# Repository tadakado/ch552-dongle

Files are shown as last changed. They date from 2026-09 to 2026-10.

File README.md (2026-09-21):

# CH552 USB HID ダミーデバイス

USB-A 直挿し基板に載せた CH552 を、キーボード + マウスの複合 HID として
認識させ、1 分ごとにマウスを 1 ドットだけ往復させてホストのスリープを
防ぐファーム。挿すだけで動き、操作は要らない。WS2812 で状態を表示する。

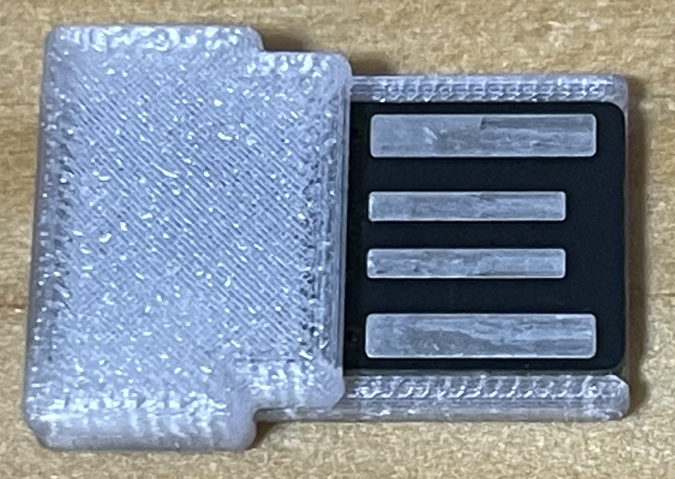
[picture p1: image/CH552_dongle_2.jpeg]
ケースまで組んだ状態


## 仕様

| | |
|---|---|
| MCU | CH552 (8051 互換 / フラッシュ 16KB のうちユーザ領域 14KB / xRAM 1KB) |
| クロック | 24MHz 固定 (VBUS 5V 直結。データシート上 24MHz は VCC 4.4V 超) |
| LED | WS2812C-2020 x1 @ P1.1 |
| タッチキー | TIN5 @ P1.7 (**既定では無効**) |
| USB | CDC-ACM + HID (キーボード + マウス) の複合デバイス |

### 既定の設定

`config.h` の既定値。挿せばすぐマウスを動かし始め、タッチキーは使わない。

| 設定 | 既定 | |
|---|---|---|
| `MODE_DEFAULT` | `MODE_WIGGLE` | 挿した直後から1分ごとにマウスを動かす |
| `TOUCH_ENABLE` | 0 | タッチキーを使わない |
| `TOUCH_LEARN_ENABLE` | 0 | タッチキーの閾値の学習をしない |
| `MODE_PERSIST` | 0 | モードを Data-Flash に覚えない |
| `CDC_DFU_1200BAUD` | 1 | 1200 baud でブートローダへ入れる |
| `SUSPEND_POLICY` | `SUSPEND_SLEEP` | ホストのサスペンド中は CH552 ごと眠る |

### モード

| モード | 動作 | LED |
|---|---|---|
| A: IDLE | 何もしない (HID として繋がっているだけ) | 緑 |
| B: WIGGLE | 1 分ごとにマウスを右へ 1、さらに 1 分後に左へ 1、を繰り返す | 赤 |

既定では**挿した直後からモード B** で、1 分後から動き始める。
切り替えはコンソールの `t` で行う (タッチキーを有効にすれば短押しでも
切り替えられる)。`MODE_DEFAULT` を `MODE_IDLE` にすると A から始まる。

切り替えた瞬間から 1 分を数え直すので、切り替えた直後にいきなり動くことは
ない。サスペンドなどで送れなかった場合は、溜まった回数をまとめて撃たずに
復帰後 1 回だけ動かして、そこから改めて 1 分を数える。

### LED の見方

| 表示 | 意味 |
|---|---|
| 消灯 | ホストがサスペンド中 (最優先) |
| 橙の呼吸 | まだ列挙されていない (SET_CONFIGURATION 未達) |
| 緑の呼吸 | モード A |
| 赤の呼吸 | モード B |

呼吸は 2.56 秒で一往復、最大輝度は 0x40。
タッチキーを有効にしたときの表示は「タッチキー (任意)」の節を参照。

### DFU (ブートローダ) への入り方

既定のビルドでは 3 系統。

1. **コンソールで `b` を入力。**
2. **1200 baud トリガ** (`CDC_DFU_1200BAUD`) — 開いて閉じるだけでよい。

   ```sh
   stty -f /dev/cu.usbmodemXXXX 1200
   ```

   CDC の SET_CONTROL_LINE_STATE で DTR が落ちたときに、ボーレートが 1200 なら
   0x3800 へ飛ぶ。Arduino Leonardo と同じ流儀。`screen` で入る場合は
   `Ctrl-A` → `K` で閉じること (`Ctrl-A` → `D` の detach ではポートが開いたままで
   DTR が落ちない)。

   **成功しても合図は出ない。** LED が消え、`/dev/cu.usbmodem*` が消えるだけ
   なので、失敗と見分けがつかない。WCH の ISP デバイス (VID 0x4348 /
   PID 0x55E0) が見えていれば入っている。

   ```sh
   ioreg -p IOUSB -l | grep -q 'idVendor" = 17224' && echo "ブートローダ"
   ```

   macOS の `/dev/cu.usbmodem*` は誰でも開けるので、ローカルの任意の
   プロセスがこのデバイスをブートローダに落とせる。0 にしても
   コンソールの `b` は残る (こちらも CDC を開ければ誰でも打てる)。
3. **ハードウェア** — D+ の 10kΩ プルアップパッドを短絡したまま挿す。
   ファームが USB ごと落ちたときの最後の砦なので、基板から省かないこと。

タッチキーを有効にすると、長押し 3 秒 (`TOUCH_LONGPRESS_DFU`) が 4 つめの
入口になる。

入ってしまったときは抜き差しすれば通常のファームに戻る。

## タッチキー (任意)

既定では無効。`TOUCH_ENABLE` を 1 にすると使える。

| 保持時間 | 触れている間の LED | 離したときの動作 |
|---|---|---|
| 〜1.0 秒 | 青 | モード切替 |
| 1.0〜3.0 秒 | シアン | 閾値を学習 (`TOUCH_LEARN_ENABLE` が 1 のときだけ) |
| 3.0 秒〜 | 白の点滅 | 何も起きない。3.6 秒まで持てばブートローダへ |

`TOUCH_LEARN_ENABLE` が 0 のときはシアンの区間ごと短押しに含まれ、
3.0 秒未満ならモード切替になる。学習が成功するとマゼンタ、採用されな
かったときは黄が点滅する。学習の書き込みは電源 ON から 2 回まで。

タッチキーを有効にすると、呼吸は指を近づけると明るくなり、閾値に
達した時点で 0x40 に張り付く。ホストのサスペンド中はタッチも効かない。

閾値は Data-Flash の保存値 > `TOUCH_THRESHOLD_DEFAULT` (0 以外のとき) >
起動時のノイズ実測からの自動決定、の順で決まる。手で決めるには
コンソールで `m` を流しながら指を当てて delta のピークを見て、`+` `-` で
合わせて `s` で焼く。`i` の `src=` で出どころが分かる。

## ハードウェア

基板は **EasyEDA Pro**、ケースは **Fusion 360** で設計した。
設計データは `hardware/` (基板) と `case/` (ケース) に置いてある。

### 基板 (EasyEDA Pro)

基板の外形は **18.80 x 9.55mm**。

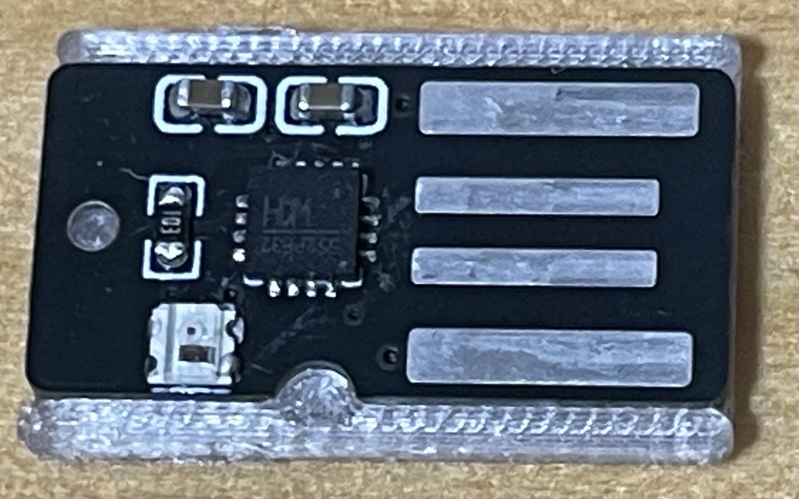
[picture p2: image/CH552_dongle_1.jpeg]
枠に入れた基板 (部品面)


右の 4 つが USB-A の接点、中央が CH552P、左下が WS2812C-2020。
まわりを囲っているグレーの部品がケースの枠 (shim)。

| | |
|---|---|
| `hardware/CH552_dongle.epro2` | EasyEDA Pro のプロジェクト |
| `hardware/CH552_dongle_gerber.zip` | Gerber + ドリル |
| `hardware/CH552_dongle_BOM.csv` | 部品表 (LCSC 品番付き) |
| `hardware/CH552_dongle_schematic.pdf` | 回路図 |

### ケース (Fusion 360)

ケースは 2 部品。`case/` に置いてある。組んだ状態は冒頭の写真を参照。

| | |
|---|---|
| `case/CH552_dongle.f3d` | Fusion のファイル。 |
| `case/CH552_dongle.step` | STEP |
| `case/CH552_dongle_shim.3mf` | 印刷用。USB-A 側の枠 18.70 x 12.00 x 1.80mm |
| `case/CH552_dongle_cover.3mf` | 印刷用。本体側のカバー 10.30 x 14.00 x 3.90mm |

### 印刷

| | |
|---|---|
| プリンタ | Bambu Lab A1 |
| ノズル | **0.2mm** |
| 積層ピッチ | 0.1mm |
| 材質 | PETG |

## ビルド

```sh
brew install sdcc
make                # build/fw.bin
make size           # コードサイズと残量
make timing         # 生成コードからサイクル数を数え直す検査 (下記)
```

対応クロックは 24MHz と 16MHz。`config.h` の `FREQ_SYS` が唯一の出所で、
Makefile にも検査ツールにも同じ値は書かない (片方だけ変えると、実機と
検査で周波数が違うのに合格が出る)。12MHz 以下は WS2812 の NOP 数も
`delay_us` の NOP 数も用意していないので `#error` にしてある。

## 書き込み

```sh
uv tool install ch55xtool
make flash
```

`flash` は `timing` に依存させてある。周期はリンク配置で変わりうるもの
なので、検査を通っていない `.bin` は焼けない。

`ch55xtool` は GPL-3 だが独立したプログラムなので、このファームのライセンスには影響しない。

## ライセンスについて

構造の参考にしたもの (コードのコピーはしていない):

- rikka0w0/CH55x_USB_CompositeDevice (MIT) — 複合デバイスの記述子の並べ方と EP0 ディスパッチ
- ch55xduino (LGPL-2.1) — 1200 baud で DFU に飛ぶ「手順」と、WS2812 で T1H を
  長めに振るという考え方 (実装は別物。あちらは `jc` で分岐、こちらは `mov bit,c` で分岐なし)
- WCH「CH55X 汇编指令说明」 — 命令のバイト数と周期数

## USB の作り

CDC-ACM と HID の複合デバイス。インタフェースは 3 本で、CDC の 2 本は
IAD (Interface Association Descriptor) で束ねている。

| インタフェース | クラス | 端点 |
|---|---|---|
| IF0 | CDC Communications (ACM) | EP3 IN (通知、未使用) |
| IF1 | CDC Data | EP2 IN / EP2 OUT (バルク 64) |
| IF2 | HID | EP1 IN (割り込み 16, 10ms) |

キーボードとマウスを 2 つのインタフェースに分けず、**1 つの HID
インタフェースに Report ID で多重**している (ID 1 = キーボード 9 バイト、
ID 2 = マウス 5 バイト)。理由は端点と USB RAM を CDC のために空けて
おくため。ホストからはどちらも普通に見える。

## CDC コンソール

```sh
screen /dev/cu.usbmodem* 115200
```

ポートを開くと自動でヘルプと現在値が出る。1 文字コマンド。

| キー | 動作 |
|---|---|
| `i` | 現在値 (閾値とその出所、ホストから届いた LED 状態、シリアル番号など) |
| `t` | モード A / B の切り替え |
| `j` | 動作確認のマウスジグル |
| `k` | 空のキーボードレポートを 1 回送る (何も打鍵されない) |
| `b` | ブートローダへ |
| `m` | delta の連続表示 on/off (タッチキー有効時) |
| `+` / `-` | 閾値を ±10 (タッチキー有効時) |
| `s` | 現在の閾値を Data-Flash に保存 (タッチキー有効時) |
| `c` | 保存値を消して自動決定に戻す (タッチキー有効時) |
| `z` | ベースラインを取り直す (タッチキー有効時) |

`i` の `src=` は閾値の出どころ。

| 表示 | 意味 |
|---|---|
| `auto` | 起動時のノイズ測定から決めた |
| `config` | `config.h` の `TOUCH_THRESHOLD_DEFAULT` |
| `flash` | Data-Flash に保存された値。**電源を入れ直しても同じ** |
| `unsaved` | 動いている値が Data-Flash の記録と食い違っている |

## 構成

```
README.md             このファイル
config.h              基板ごとに変わる設定 (ピン、クロック、色、輝度)
include/ch552.h       SFR 定義。データシートの SFR 表から自前で起こしたもの
src/sys.c             クロック設定、遅延、ブートローダジャンプ
src/tick.c            Timer2 のオートリロードによる 1ms タイムベース
src/neo.c             WS2812 ビットバン
src/touch.c           タッチキー。ベースライン追従、閾値の自動決定と学習
src/dflash.c          Data-Flash (128 バイト) の読み書き
src/usb.c             USB デバイスコア。制御転送と端点管理
src/usb_desc.c        記述子 (デバイス / 複合コンフィグ / HID レポート / 文字列)
src/hid.c             HID レポートの組み立てと送出
src/cdc.c             CDC のリングバッファ
src/console.c         CDC 経由の 1 文字コマンド
src/mode.c            モード A / B の状態機械
src/breathe_lut.h     呼吸パターンの輝度テーブル (tools/gen_lut.py で生成)
src/main.c            メインループ
tools/gen_lut.py      輝度テーブル生成
tools/ch55x.py        リストファイルから命令周期を数える共通部品
tools/neo_timing.py   WS2812 のビットタイミング検査 (make timing)
tools/delay_check.py  delay_us の較正検査 (make timing)
tools/naked_check.py  __naked 関数のレジスタ退避検査 (make timing)
tools/oseg_check.py   割り込みの呼び出し木が OSEG に触れない検査 (make timing)
tools/touch_sim.py    タッチ状態機械の模擬 (make touchsim)
hardware/             EasyEDA Pro の設計データ (回路図、基板、Gerber、BOM)
case/                 Fusion 360 のケース (.f3d / STEP / 印刷用 3MF x2)
image/                実物の写真
```

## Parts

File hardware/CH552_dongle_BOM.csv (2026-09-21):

No. | Quantity | Comment | Designator | Footprint | Value | Manufacturer Part | Manufacturer | Supplier Part | Supplier
1 | 2 | 100nF | C1,C2 | C0603 | 100nF
2 | 1 | Jumper_Pad_2 | JP1 | JUMPER-PAD-2 |  |  |  | undefined
3 | 1 | SMD-Wire-Pad-10x3mm | P1 | SMD-PAD-10X3
4 | 1 | 10K | R1 | R0603 | 10K
5 | 1 | CH552P | U1 | VQFN-16_L3.0-W3.0-P0.50-BL-EP1.7 |  | CH552P | WCH | C968536 | LCSC
6 | 1 | WS2812C-2020-V6 | U3 | LED-SMD_4P-L2.2-W2.0-P1.00_WS2815C-2020-4P |  | WS2812C-2020-V6 | worldsemi | C55109522 | LCSC
7 | 1 | USBPCB | X1 | USB-A-PCB

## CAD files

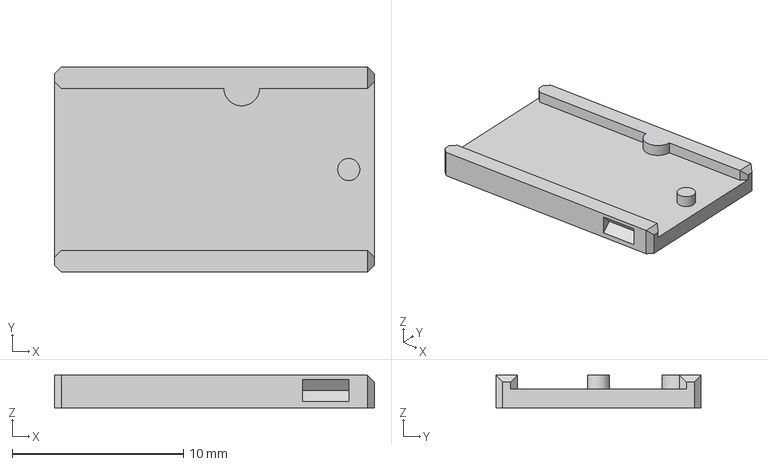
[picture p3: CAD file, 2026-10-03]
case/CH552_dongle_shim.3mf
18.7 x 12.0 x 1.90 mm

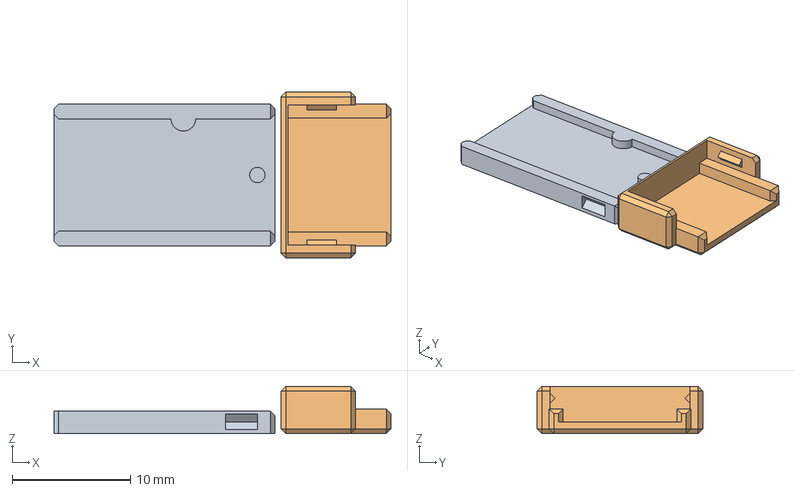
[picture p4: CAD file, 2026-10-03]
case/CH552_dongle.step
28.5 x 14.0 x 4.00 mm

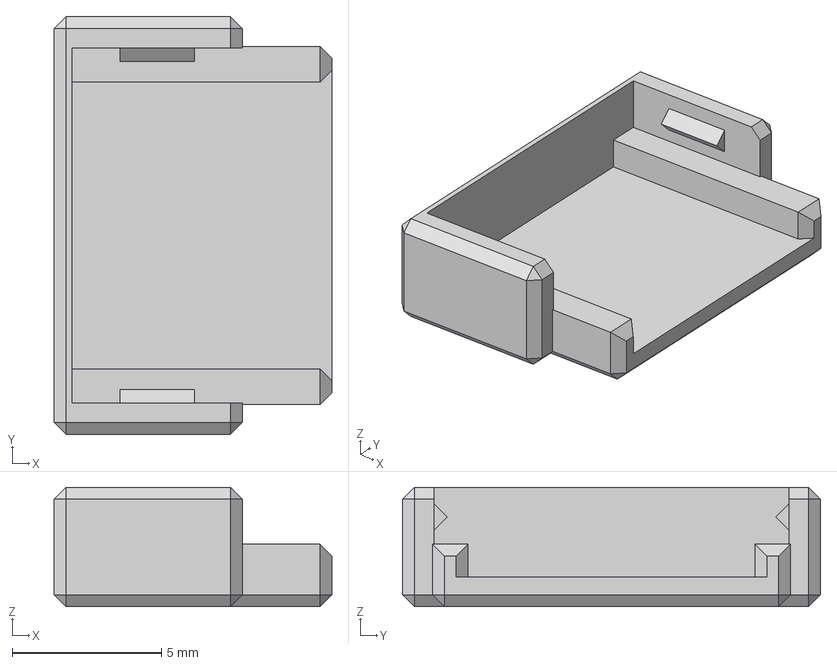
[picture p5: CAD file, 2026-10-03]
case/CH552_dongle_cover.3mf
9.30 x 14.0 x 4.00 mm

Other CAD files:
case/CH552_dongle.f3d

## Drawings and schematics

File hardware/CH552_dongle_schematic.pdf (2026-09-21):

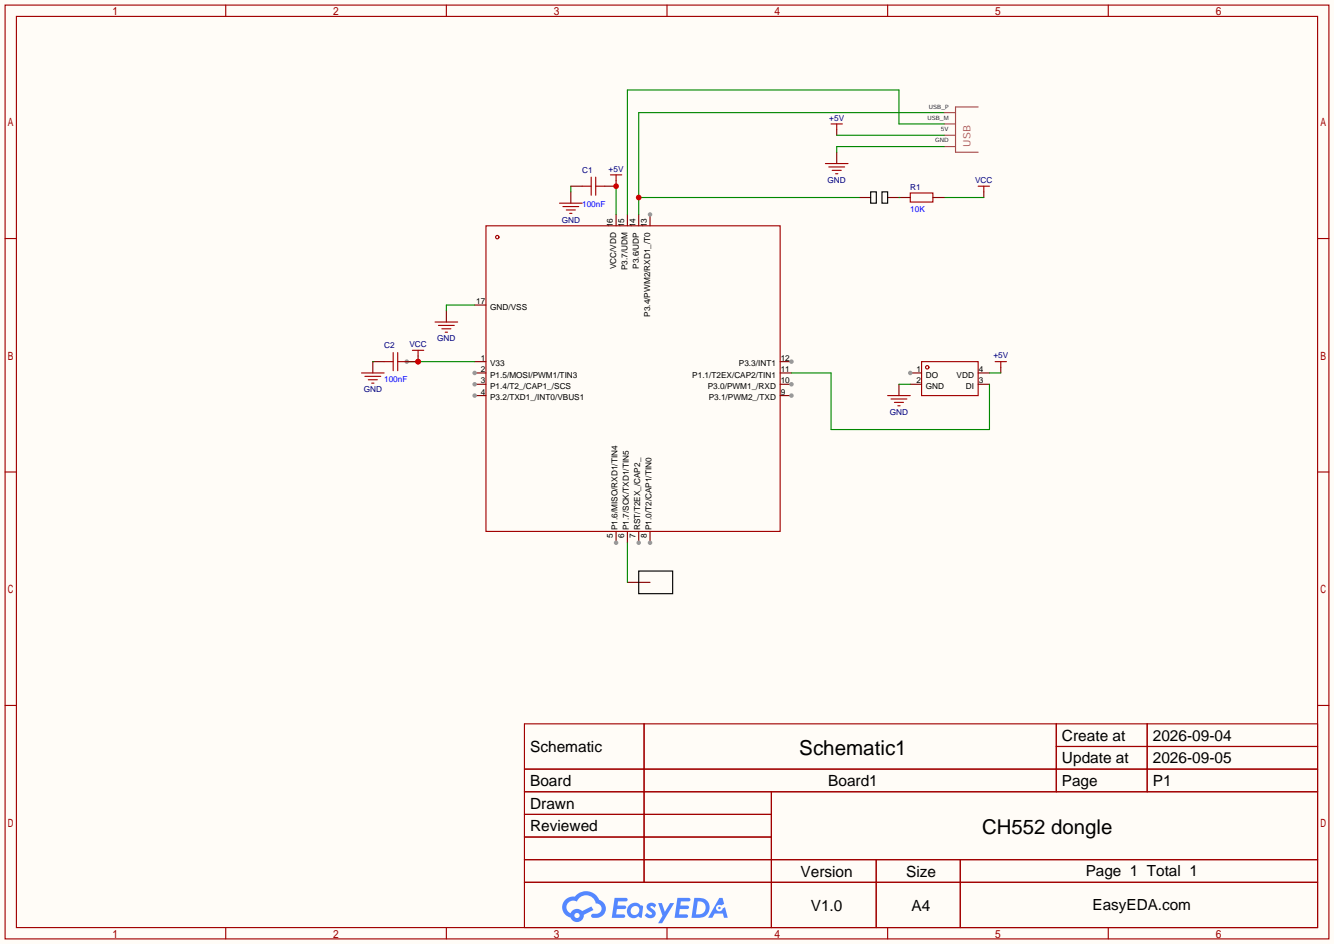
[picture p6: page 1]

Schematic | Schematic1 | Create at | 2026-09-04

Update at | 2026-09-05

Board | Board1 | Page | P1
Drawn | | CH552 dongle
Reviewed

Version | Size | Page 1 Total 1
V1.0 | A4 | EasyEDA.com

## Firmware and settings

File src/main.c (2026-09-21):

/* SPDX-License-Identifier: MIT */
/*
 * main.c - CH552 USB HID ダミーデバイス
 *
 * モード:
 *   A IDLE    何もしない。USB HID として繋がっているだけ。LED 緑
 *   B WIGGLE  1 分ごとにマウスを右へ 1、さらに 1 分後に左へ 1。LED 赤
 *
 * タッチの短押しで A <-> B を切り替える。
 *
 * LED の見方 (上にあるものが下を上書きする):
 *   消灯          ホストがサスペンド中。**これが最優先**。サスペンドの
 *                 判定はループの先頭にあり、以下の表示には届かない。
 *                 触れている最中に眠られると青も白も消える
 *   白 1 回        サスペンド中にタッチしてホストを起こそうとした
 *                 (SUSPEND_POLICY = SUSPEND_WAKE のときだけ)
 *   白の点滅      サスペンド中の長押し 3 秒成立
 *                 (SUSPEND_POLICY = SUSPEND_WAKE のときだけ)
 *   --- ここから下はホストが起きているときの表示 ---
 *   マゼンタ点滅  閾値の学習に成功して Data-Flash に保存した
 *                 12.5Hz を 600ms (8 回点滅)
 *   黄の点滅      学習を試みたが採用できなかった (値が妥当でない、
 *                 または Data-Flash に焼けなかった)
 *                 12.5Hz を 400ms (5 回点滅)
 *   白の点滅      長押し 3 秒成立。6.2Hz を 600ms (4 回点滅) して
 *                 消灯し、ブートローダへ飛ぶ
 *   青のべた点灯  タッチ検出中 (3 秒未満)
 *   橙の呼吸      まだ列挙されていない (SET_CONFIGURATION 未達)
 *   モード色の呼吸 列挙済み。モード A = 緑、モード B = 赤。
 *                 指を近づけると呼吸を突き抜けて明るくなる
 *
 * 呼吸は 2.56 秒で一往復。ガンマ補正の下端が 0 なので、1 周期あたり
 * 500ms ほどは完全に消灯する。最大輝度は 0x40。
 *
 * 閾値を変える方法は 3 つある。
 *   1. 実機だけで完結: 1.0〜2.5 秒のあいだ触れて離す。その押下で出た
 *      delta の最大値の半分が新しい閾値になり、Data-Flash に焼かれる。
 *   2. config.h の TOUCH_THRESHOLD_DEFAULT を 0 以外にして焼き直す。
 *   3. CDC のコンソールから + / - で動かして s で保存する。
 * Data-Flash の値は config.h より優先される。
 */
#include "ch552.h"
#include "config.h"
#include "sys.h"
#include "tick.h"
#include "neo.h"
#include "touch.h"
#include "usb.h"
#include "hid.h"
#include "cdc.h"
#include "console.h"
#include "mode.h"
#include "breathe_lut.h"

#define BREATHE_STEP_MS (BREATHE_MS / BREATHE_STEPS)

/* コンソールの j で走らせる動作確認用のジグル */
#define TEST_JIGGLE_GAP_MS 300

enum {
    JIG_IDLE = 0,
    JIG_SEND_RIGHT,
    JIG_WAIT,
    JIG_SEND_LEFT
};

/*
 * 近接量を LED の明るさに写す。
 * delta が閾値に対してどこまで来ているかを 0..NEO_MAX で返す。
 */
static uint8_t proximity_level(void)
{
    uint16_t d = touch_delta();
    uint16_t thr = touch_threshold();

    if (d == 0 || thr == 0) {
        return 0;
    }
    if (d >= thr) {
        return NEO_MAX;
    }
    return (uint8_t)((uint32_t)d * NEO_MAX / thr);
}

void main(void)
{
    uint32_t next_frame = 0;
    uint32_t jig_at = 0;
    uint8_t phase = 0;
    uint8_t frames_in_step = 0;
    uint8_t blink = 0;
#if TOUCH_LEARN_ENABLE
    uint8_t flash_frames = 0;
    uint8_t flash_ok = 0;
#endif
    uint8_t jig_state = JIG_IDLE;
    uint8_t was_suspended = 0;
#if SUSPEND_POLICY == SUSPEND_WAKE
    uint8_t swallow_release = 0;
#endif
    uint32_t suspend_at = 0;
    uint16_t last_hold_ms = 0;

    const uint8_t frames_per_step =
        (BREATHE_STEP_MS + NEO_FRAME_MS - 1) / NEO_FRAME_MS;

    sys_init();
    neo_init();
    tick_init();
    EA = 1;

    /*
     * タッチの較正は指を触れていない前提。72ms (やり直しが入ると最悪
     * 216ms、測定系が黙っていると 576ms) ブロックするので、USB を
     * 上げる前に済ませておく。列挙が始まってから止まるより挿す前に
     * 終わっている方が行儀が良い。この時点ではまだ D+ のプルアップを
     * 上げていないので、ホストからはデバイスが見えていない。
     */
#if TOUCH_ENABLE
    touch_init();
#endif
    mode_init();
    console_init();
    usb_init();

    /*
     * 餌やりが要る処理はここから。ブロックの長い初期化 (touch_init の
     * 72〜576ms) を済ませてから有効にする。順序を逆にすると、
     * タッチが黙っている個体で列挙前にリセットを繰り返すことになり、
     * 1200baud も長押しも届かない = ブートローダへの入口が
     * ハードウェアのパッドだけになる。
     */
    sys_watchdog_init();

    for (;;) {
        uint32_t now;

        sys_watchdog_feed();

        /* --- ホストがサスペンドしている間 --------------------------- */
        /*
         * 列挙済みかどうかは見ない。USB の 500uA 制限はサスペンド中の
         * デバイス全部にかかるもので、未構成なら免除されるわけではない。
         * 眠っている PC の給電ポートに挿したまま放置すると、
         * その条件を入れていると 24MHz で回り続けて電池を舐める。
         *
         * バスに活動がある限り suspended は立たないので、列挙の途中で
         * 眠ることはない。橙の呼吸 (未列挙の表示) もその間は出続ける。
         */
        if (usb_is_suspended()) {
            if (!was_suspended) {
                /*
                 * 消灯は 1 回だけ送れば足りるが、**直前のフレームとの
                 * 間隔が保証されていない**。サスペンドが立つのは
                 * 20ms のフレーム周期のどこでもよく、直前の描画から
                 * 280us 以内だと、この 24bit は「2 個目の LED ぶり」と
                 * 見なされて DOUT に素通りする。1 灯構成では何も起きず、
                 * 直前の呼吸のフレームが点いたままホストのスリープ中
                 * ずっと光り続ける (サスペンド 70 回に 1 回程度)。
                 * 500uA の話をしておいて光らせたままでは意味がない。
                 * NEO_SUSPEND_LEVEL は既定 0 なので真っ暗になる。
                 */
                neo_latch();
                neo_show(mode_color_r(), mode_color_g(), mode_color_b(),
                         NEO_SUSPEND_LEVEL);
                was_suspended = 1;
                suspend_at = tick_now();
                /*
                 * 通常運転中は押下イベントを誰も consume しないので、
                 * 最後に触ったぶんが溜まったままここに来る。掃除して
                 * おかないと、指を離してからホストが眠った直後に
                 * 「古い押下」でリモートウェイクアップを撃ってしまい、
                 * 触ってもいないのに Mac が起きる。離しも同様に捨てる。
                 */
#if TOUCH_ENABLE
                touch_clear_events();
#endif
                last_hold_ms = 0;
#if SUSPEND_POLICY == SUSPEND_WAKE
                /*
                 * この先の長押し予告も同じフレーム変数で間引いている。
                 * 期限を過ぎたまま持ち越すと、指を置いたまま眠られた
                 * 場合に予告の 1 フレーム目が消灯の直後に出てしまい、
                 * これも 280us に届かず素通りする。1 周期ぶん空ける。
                 */
                next_frame = suspend_at + NEO_FRAME_MS;
#endif
            }

#if SUSPEND_POLICY == SUSPEND_SLEEP
            /*
             * USB イベントが来るまで眠る。眠っている間はタッチもタイマも
             * 止まるので、ここから先を回しても意味がない。
             *
             * 判定ごと割り込み禁止の中でやる。上の usb_is_suspended() は
             * 割り込み有効のまま読んでいるので、そこから sys_sleep() に
             * 入るまでの間にレジュームが来る余地がある。ホストが起きて
             * いるのにこちらだけ眠る、という状態になりうる (実際には
             * レジューム後の SOF で起きるので自己修復するが、隙間は
             * 塞いでおく)。
             */
            EA = 0;
            if (usb_is_suspended()) {
                sys_sleep();
            }
            EA = 1;
#else
            /*
             * 起きたまま待ち、タッチされたらホストを起こす。
             * ホストが SET_FEATURE(DEVICE_REMOTE_WAKEUP) で許可して
             * いなければ usb_remote_wakeup() は何もしない。
             */
#if TOUCH_ENABLE
            touch_poll();
            /*
             * ガードを先に見ること。&& を逆に書くと、時間の条件を
             * 満たさない場合でも touch_take_press() が先に走って
             * 押下イベントを食べてしまう。すると swallow_release が
             * 立たないまま離しだけが残り、復帰後の最初のループで
             * held = 0 の短押しと見なされてモードが切り替わる。
             * 「起こそうとしただけなのにモード B に入っていた」になる。
             */
            if ((int32_t)(tick_now() - suspend_at) >= WAKEUP_GUARD_MS &&
                touch_take_press()) {
                if (usb_remote_wakeup()) {
                    /*
                     * 起こしにいったことが分かるように 1 回光らせる。
                     * ホストが起きなかった場合、これだけが手がかりになる。
                     */
                    neo_show(COLOR_DFU_R, COLOR_DFU_G, COLOR_DFU_B, NEO_MAX);
                    delay_ms(80);
                    neo_show(0, 0, 0, 0);
                    neo_latch();
                }
                /*
                 * 起こすために触ったぶんでモードまで切り替わると
                 * 驚くので、この押下に対応する離しは食べてしまう。
                 * 長押しの DFU は保持時間で判定しているので影響しない。
                 */
                swallow_release = 1;
            }

            /*
             * サスペンド中も長押し DFU を効かせる。README の比較表が
             * SUSPEND_WAKE では「長押し DFU が効く」と書いている以上、
             * ここで continue して判定に届かないのは食い違い。
             * ホストが起床を許可していない場合、眠ったままの Mac から
             * 書き直す唯一の入口がこれになる。
             */
            if (touch_is_down()) {
                uint16_t held = touch_hold_ms();

                if (held >= TOUCH_LONGPRESS_MS) {
                    /*
                     * 通常ループと同じく 20ms に間引く。毎周回 (数十 us)
                     * 送ると連続フレームの間に 280us の低区間が入らず、
                     * WS2812 がラッチしないので予告の白点滅が見えない。
                     * さらに 33us の EA=0 と P1 の高速トグルを回し続けて
                     * タッチ測定にノイズを乗せることになる。
                     */
                    uint32_t now2 = tick_now();

                    if ((int32_t)(now2 - next_frame) >= 0) {
                        next_frame = now2 + NEO_FRAME_MS;
                        blink++;
                        neo_show(COLOR_DFU_R, COLOR_DFU_G, COLOR_DFU_B,
                                 (blink & 0x04) ? NEO_MAX : 0);
                    }
#if TOUCH_LONGPRESS_DFU
                    if (held >= (TOUCH_LONGPRESS_MS + 600)) {
                        neo_latch();
                        neo_show(COLOR_DFU_R, COLOR_DFU_G, COLOR_DFU_B, 0);
                        neo_latch();
                        sys_jump_bootloader(); /* 戻ってこない */
                    }
#endif
                }
            }
#endif /* TOUCH_ENABLE */
#endif /* SUSPEND_POLICY == SUSPEND_WAKE */
            continue;
        }
        if (was_suspended) {
            was_suspended = 0;

            /*
             * 眠っている間はベースライン追従が止まる。復帰したときに
             * 温度や湿度で生値が閾値ぶん下がっていると、指も触れて
             * いないのに押下判定が立つ。押下中はベースラインを
             * 追従させない作りなので自分では戻れず、押しっぱなし救済
             * (30 秒) より先に長押し DFU (3.6 秒) に届いてしまう。
             * つまり **Mac が復帰するたびに勝手にブートローダへ落ちる**。
             *
             * 測り直せば済む。指が乗っていた場合は delta が 0 側に
             * 倒れるだけなので安全側。72ms (やり直しが入ると 216ms)
             * かかる。touch_recalibrate() は中で餌をやるので、
             * 同じ周回でコンソールの z が続いても足りなくならない。
             */
#if TOUCH_ENABLE
            touch_recalibrate();
            touch_clear_events();
#endif
            last_hold_ms = 0;
#if SUSPEND_POLICY == SUSPEND_WAKE && TOUCH_ENABLE
            /*
             * 起こすために触ったぶんの離しを食べる旗も下ろす。
             * 残したままだと、復帰後の最初の短押しが食べられて
             * モードが切り替わらない。押下側は touch_clear_events()
             * で消しているので、対応する離しはもう来ない。
             */
            swallow_release = 0;
#endif

            /* 復帰したらすぐ描き直す */
            next_frame = tick_now();
        }

#if TOUCH_ENABLE
        touch_poll();
#endif
        console_poll();
        cdc_flush();

        /*
         * 1200 baud で開いて閉じる合図。割り込みの中では飛べないので
         * ここで拾う。ホストから見ると、ポートを閉じた直後に
         * デバイスが消えて ISP デバイスとして戻ってくる。
         */
        if (usb_dfu_requested()) {
            /*
             * ここもフレーム周期の外なので、前後にラッチを置く。
             * 前を省くと消灯が素通りして、モード色のまま ISP に入る。
             */
            neo_latch();
            neo_show(COLOR_DFU_R, COLOR_DFU_G, COLOR_DFU_B, 0);
            neo_latch();
            sys_jump_bootloader(); /* 戻ってこない */
        }

        if (console_take_jiggle()) {
            jig_state = JIG_SEND_RIGHT;
        }

        /* モード B の 1 分ごとの往復 */
        mode_poll();

        /* --- タッチのジェスチャ処理 -------------------------------- */
#if TOUCH_ENABLE
        if (touch_take_release()) {
            uint16_t held = last_hold_ms;

            /*
             * 使ったら必ず捨てる。残しておくと、指を置いたまま
             * ホストがサスペンドしてスリープに入り、指を離した後で
             * 復帰したときに、古い保持時間で離しが成立する。
             * 1.5 秒が残っていれば復帰のたびに閾値学習が走り、
             * せっかく合わせた保存値を上書きしてしまう。
             * 押しっぱなし救済 (touch.c) も押下無しで離しを立てるので、
             * そちらの経路でも同じことが起きる。
             */
            last_hold_ms = 0;

#if SUSPEND_POLICY == SUSPEND_WAKE && TOUCH_ENABLE
            if (swallow_release) {
                /* ホストを起こすために触ったぶん。何もしない */
                swallow_release = 0;
            } else
#endif
            if (held < TOUCH_SHORT_MAX_MS) {
                /* 短押し (青のうちに離した): モード切替 */
                mode_toggle();
            }
#if TOUCH_LEARN_ENABLE
            else if (held < TOUCH_LONGPRESS_MS) {
                /*
                 * 学習窓 (シアンのうちに離した)。上限が長押しの
                 * 敷居そのものなので、シアンで離せば必ずここに入る。
                 * 白が出る前に離せたなら学習できている、と手元だけで
                 * 判断できるのはこの一致があるため。
                 *
                 * 候補を作る -> 焼けたら採用、の順にする。
                 * touch_save_threshold() は成功したときだけ動作中の
                 * 閾値を差し替えるので、flash_ok がそのまま
                 * 「採用できたか」になり、黄 = 不採用 が嘘にならない。
                 */
                uint16_t thr = touch_peak_threshold(TOUCH_LEARN_DIVISOR);

                /*
                 * touch_learn_threshold() は 0 以外を返したときだけ
                 * その値が有効になっている。既に同じ値が入っていて
                 * 焼かなかった場合 (TOUCH_SAVE_SAME) も 0 以外なので、
                 * マゼンタで正しい。上限に達していた場合は 0 が返り、
                 * 黄になる。
                 */
                flash_ok = (thr != 0)
                             ? (touch_learn_threshold(thr) != TOUCH_SAVE_FAIL)
                             : 0;
                flash_frames = flash_ok ? 30 : 20; /* 600ms / 400ms */
            }
#endif
        }
        if (touch_is_down()) {
            last_hold_ms = touch_hold_ms();
        }
#endif /* TOUCH_ENABLE */

        now = tick_now();

        /* --- 動作確認のジグル -------------------------------------- */
        /*
         * hid_mouse_move() は EP1 が空いていないと 0 を返す。
         * 送れるまで状態を進めないので、取りこぼしは起きない。
         */
        switch (jig_state) {
        case JIG_SEND_RIGHT:
            if (hid_mouse_move(1, 0, 0, 0)) {
                jig_at = now + TEST_JIGGLE_GAP_MS;
                jig_state = JIG_WAIT;
            }
            break;
        case JIG_WAIT:
            if ((int32_t)(now - jig_at) >= 0) {
                jig_state = JIG_SEND_LEFT;
            }
            break;
        case JIG_SEND_LEFT:
            if (hid_mouse_move(-1, 0, 0, 0)) {
                jig_state = JIG_IDLE;
            }
            break;
        default:
            break;
        }

        /* --- LED ---------------------------------------------------- */
        if ((int32_t)(now - next_frame) < 0) {
            continue;
        }
        next_frame = now + NEO_FRAME_MS;
        blink++;

#if TOUCH_LEARN_ENABLE
        if (flash_frames != 0) {
            flash_frames--;
            if (flash_ok) {
                neo_show(COLOR_LEARN_R, COLOR_LEARN_G, COLOR_LEARN_B,
                         (blink & 0x02) ? NEO_MAX : 0);
            } else {
                /*
                 * 失敗は黄で点滅させる。以前は赤のべた点灯だったが、
                 * モード B の赤い呼吸のなかで 200ms だけ全点灯しても
                 * ほとんど見分けがつかなかった。点滅させておけば
                 * どのモードの最中でも「何か起きた」と分かる。
                 */
                neo_show(COLOR_FAIL_R, COLOR_FAIL_G, COLOR_FAIL_B,
                         (blink & 0x02) ? NEO_MAX : 0);
            }
        } else
#endif
#if TOUCH_ENABLE
        if (touch_is_down()) {
            uint16_t held = touch_hold_ms();

            if (held >= TOUCH_LONGPRESS_MS) {
                neo_show(COLOR_DFU_R, COLOR_DFU_G, COLOR_DFU_B,
                         (blink & 0x04) ? NEO_MAX : 0);
#if TOUCH_LONGPRESS_DFU
                if (held >= (TOUCH_LONGPRESS_MS + 600)) {
                    /*
                     * 直前の予告点滅と連続で送ることになるので、
                     * あいだにリセット時間を入れる。入れないと
                     * 2 回目の 24bit が「2 個目の LED ぶん」と
                     * 見なされて素通りし、消灯が反映されないまま
                     * ブートローダに入る。
                     */
                    neo_latch();
                    neo_show(COLOR_DFU_R, COLOR_DFU_G, COLOR_DFU_B, 0);
                    neo_latch();
                    sys_jump_bootloader(); /* 戻ってこない */
                }
#endif
            }
#if TOUCH_LEARN_ENABLE
            else if (held >= TOUCH_LEARN_MIN_MS) {
                /*
                 * 学習窓に入った合図。ここで離せば閾値を学習する。
                 * 窓の出口 (白点滅) と対にして見せるためのもので、
                 * TOUCH_DEBUG_LED では消さない。押している最中の色と
                 * 離したときの結果が対応していないと、白を見る前に
                 * 離せたかどうかでしか成否を判断できなくなる。
                 */
                neo_show(COLOR_LEARNWIN_R, COLOR_LEARNWIN_G,
                         COLOR_LEARNWIN_B, NEO_MAX);
            }
#endif
            else {
#if TOUCH_DEBUG_LED
                /* 触れている間は青。閾値を詰めるときの視認用 */
                neo_show(COLOR_TOUCH_R, COLOR_TOUCH_G, COLOR_TOUCH_B, NEO_MAX);
#else
                /* 表示を切ってあるときはモードの色のまま光らせておく */
                neo_show(mode_color_r(), mode_color_g(), mode_color_b(),
                         NEO_MAX);
#endif
            }
        } else
#endif /* TOUCH_ENABLE */
        {
            /*
             * 呼吸の明るさと近接量の大きい方を採る。
             * 列挙前は橙、列挙後はモードの色。挿しただけで状態が目で分かる。
             */
            uint8_t breath = breathe_lut[phase];
#if TOUCH_DEBUG_LED
            uint8_t prox = proximity_level();
            uint8_t level = (prox > breath) ? prox : breath;
#else
            uint8_t level = breath;
#endif

            /*
             * サスペンド中はループの先頭で continue しているので、
             * ここに来る時点でホストは起きている。
             */
            if (usb_is_configured()) {
                neo_show(mode_color_r(), mode_color_g(), mode_color_b(),
                         level);
            } else {
                neo_show(COLOR_NOUSB_R, COLOR_NOUSB_G, COLOR_NOUSB_B, level);
            }
        }

        if (++frames_in_step >= frames_per_step) {
            frames_in_step = 0;
            phase = (uint8_t)((phase + 1) & (BREATHE_STEPS - 1));
        }
    }
}

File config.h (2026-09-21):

/* SPDX-License-Identifier: MIT */
/*
 * config.h - 基板ごとに変わる設定はすべてここに集約する。
 *
 * 実機がまだ無い段階なので、評価ボードで代用する場合は
 * NEO_PIN / TOUCH_CH をここだけ書き換えれば済むようにしてある。
 */
#ifndef CONFIG_H
#define CONFIG_H

/* ------------------------------------------------------------------ */
/* クロック                                                            */
/* ------------------------------------------------------------------ */
/*
 * 24MHz を選ぶ理由は WS2812 のビット生成に余裕を持たせるため。
 * ただしデータシート上 24MHz は VCC 4.4V 超が条件なので、
 * VBUS(5V) 直結電源であることが前提。3.3V 動作させる基板なら
 * 16MHz (SYS_CK_16M) に落とし、NEO_T1H_NOPS 等を再調整すること。
 */
#define FREQ_SYS 24000000UL

/* ------------------------------------------------------------------ */
/* WS2812C-2020 RGB LED                                                */
/* ------------------------------------------------------------------ */
#define NEO_PORT     P1        /* データ線のポート                      */
#define NEO_BIT      1         /* P1.1                                  */
/*
 * 連結数。neo_show() は 1 個ぶん (24bit) しか送らないので、今は 1 のみ。
 * 増やすなら neo.c 側を個数ぶん回すこと。定義だけあって使われていないと
 * 「2 にしたのに 2 個目が光らない」で悩むので、ここで釘を刺しておく。
 */
#define NEO_COUNT    1

/* WS2812C-2020 のリセット時間。WS2812B の 50us より長い */
#define NEO_LATCH_US 300

/*
 * 最大輝度。ユーザ指定どおり 0x40 で頭打ちにする。
 * WS2812 は 8bit デジタルなので「アナログ階調」は
 * フレーム更新 (NEO_FRAME_MS 周期) で値を振ることで作る。
 */
#define NEO_MAX      0x40

/* 呼吸パターンの更新周期と一周にかける時間 */
#define NEO_FRAME_MS 20        /* 50Hz 更新。ちらつきは見えない          */
#define BREATHE_MS   2560      /* 64 ステップ x 40ms = 約 2.6 秒で一往復 */

/*
 * ホストがサスペンドしている間の明るさ。0 で完全消灯。
 * SUSPEND_POLICY が SUSPEND_SLEEP のときは MCU ごと眠るので、この値は
 * 眠りに入る直前に 1 フレームだけ送られる (実質 0 以外に意味はない)。
 */
#define NEO_SUSPEND_LEVEL 0

/* ------------------------------------------------------------------ */
/* タッチキー                                                          */
/* ------------------------------------------------------------------ */
/*
 * タッチキーを使うか。0 にすると測定そのものを回さない。
 *
 * 押下も離しも一切立たなくなるので、モード切替・閾値の学習・長押しの
 * DFU が全部止まる。**長押し 3 秒の DFU も無くなる**ことに注意する
 * こと。ホストを介さずにブートローダへ入る道はこれだけなので、
 * CDC_DFU_1200BAUD も 0 にしてあると、残るのは D+ の BOOT パッドを
 * 短絡して挿す方法だけになる。
 *
 * モードの切り替えはコンソールの t で引き続きできる。
 */
//#define TOUCH_ENABLE 1
#define TOUCH_ENABLE 0

/*
 * TIN 番号で指定する。レジスタに書く値は +1 されるので、ここは 5 のまま。
 * (TKEY_CTRL の下位 3bit は 1 始まり: 6 = TIN5)
 */
#define TOUCH_CH     5         /* TIN5                                  */
#define TOUCH_PIN_BIT 7        /* P1.7                                  */
#define TOUCH_SAMPLE_2MS 0     /* 0 = 1ms 周期, 1 = 2ms 周期            */

/*
 * 閾値。ベースラインからの下降量 (カウント) で指定する。
 *
 *   0            -> 起動時のノイズ実測から自動決定 (推奨)
 *   0 以外の値   -> その値を固定で使う
 *
 * どちらの場合も Data-Flash に保存された値があればそちらが優先される。
 * つまり「まず自動で動かす → 実測して気に入らなければ保存値で上書き」
 * という順で詰められる。再コンパイルなしで変えたいときは
 * touch_set_threshold() + touch_save_threshold() を使う。
 *
 * 参考値として、WCH の公式サンプルは固定 100 カウントを使っている。
 */
#define TOUCH_THRESHOLD_DEFAULT 0
#define TOUCH_THRESHOLD_MIN     40    /* 自動決定時の下限               */
#define TOUCH_THRESHOLD_MAX     4000  /* 保存値の妥当性チェックにも使う */
#define TOUCH_NOISE_MULT        6     /* 閾値 = ノイズ幅 x この値       */

#define TOUCH_HYST_SHIFT     2   /* 離し判定は閾値の 3/4 (1 - 1/4)     */
#define TOUCH_DEBOUNCE       3   /* 連続 3 サンプルで確定 (3ms 以上)   */
#define TOUCH_AVG_SHIFT      2   /* 4 サンプルの IIR 移動平均          */
#define TOUCH_BASE_SHIFT     6   /* ベースライン追従 1/64              */
/*
 * WS2812 の送出と重なったサンプルを弾くために、生値は 3 点のメディアンを
 * 通してから移動平均に入れる (src/touch.c)。単発の跳びは振幅に関係なく
 * 消え、指のような連続した変化は 1ms 遅れるだけで通るので、閾値も
 * 外れ値カウンタも要らない。以前あった TOUCH_JUMP / TOUCH_OUTLIER_LIMIT は
 * そのため撤去した。
 */

/*
 * 較正の窓が信用できるノイズ幅の上限と、やり直す回数。
 * この幅を超えたら指が動いていたと見て測り直す。
 * TOUCH_NOISE_MULT が 6 なので、200 を超えると自動閾値が
 * 1200 以上になり、実質的に押せなくなる。
 */
#define TOUCH_NOISE_SANE 200
#define TOUCH_CAL_RETRY  3

/*
 * ベースライン追従の間引き。何サンプルに 1 回だけ動かすか。
 *
 * 追従の刻みは (差 >> TOUCH_BASE_SHIFT) + 1 で、下限の +1 が要る
 * (これが無いと差が 64 未満のあいだ下向きに追従できず、触ると値が
 * 下がるのだから、追従できない向きが誤検出する向きになる)。
 * ところがこれを 1ms ごとに回すと下限だけで 1000 カウント/秒になり、
 * 指の接近をベースラインが食べてしまう。Δ=200 カウントの指を
 * 200ms かけて置くと peak delta が 1.7 までしか出ず、検出しない。
 * ゆっくり置く動作は長押し (DFU) や学習ジェスチャそのものなので、
 * 「速く叩けば効くのに、置くと効かない」という分かりにくい症状になる。
 *
 * 64 に間引くと時定数が約 4 秒、下限の追従速度が 15.6 カウント/秒。
 * 温度や湿度のドリフトには十分で、1 秒かけて置いても検出する。
 */
#define TOUCH_BASE_PERIOD 64
#define TOUCH_DISCARD_SAMPLES 8  /* 較正前に捨てるサンプル数           */
#define TOUCH_CAL_SAMPLES    64  /* 較正に使うサンプル数 (= 64ms)      */
#define TOUCH_STUCK_MS    30000  /* 押しっぱなしが続いたら測り直す      */

/*
 * ジェスチャの割り当て (時間はすべて押しっぱなしの継続時間)
 *   ~1.0s        青        離すとモード切替 (A <-> B)
 *   1.0s ~ 3.0s  シアン    離すと閾値を学習して Data-Flash に保存
 *   3.0s ~       白点滅    離しても何も起きない / 3.6s でブートローダ
 *
 * 境界に「何も起きない」帯を作らないこと。触っている最中の色と
 * 離したときの結果が 1 対 1 に対応していれば、「シアンのうちに離した
 * (白を見ていない) なら学習できたはず」と手元だけで判断できる。
 * 入り口 (青 -> シアン) と出口 (シアン -> 白) の両方が見えるのが肝で、
 * 学習窓の上限を独立の定数にすると、そこから長押しまでのあいだが
 * 「シアンなのに離しても何も起きない」帯になって、この対応が崩れる。
 */
#define TOUCH_LONGPRESS_MS  3000
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

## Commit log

2026-09-21 CH552 USB HID ダミーデバイス
    USB-A 直挿し基板に載せた CH552 を、キーボード + マウスの複合 HID として
    認識させ、1 分ごとにマウスを 1 ドットだけ往復させてホストのスリープを
    防ぐ。挿すだけで動き、操作は要らない。
    ファーム:
    - CDC-ACM + HID (キーボード + マウス) の複合デバイス。24MHz 固定
    - 既定は挿した直後からモード B (赤、1 分ごとにマウスを動かす)。
    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
    [CH552_dongle.f3d, CH552_dongle.step, CH552_dongle_BOM.csv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]
2026-10-03 update case design
    [CH552_dongle.f3d, CH552_dongle.step, CH552_dongle_cover.3mf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]
